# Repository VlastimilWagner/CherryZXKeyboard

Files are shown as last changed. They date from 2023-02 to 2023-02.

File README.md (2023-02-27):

# CherryZXKeyboard

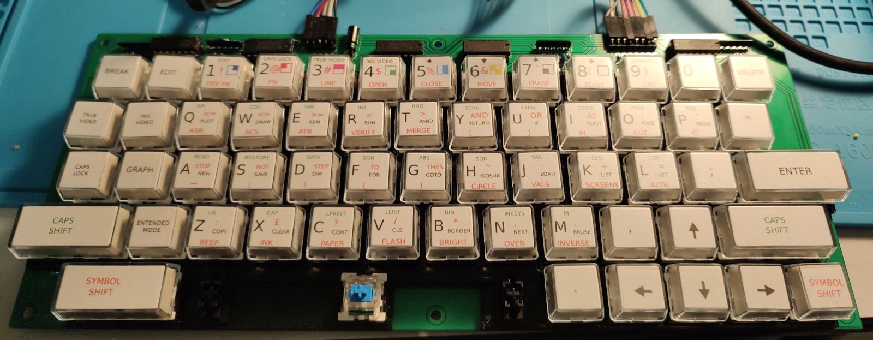
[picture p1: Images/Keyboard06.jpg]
Keyboard


The goal of the project was to create a keyboard consisting of Cherry MX keys with two-layer keycaps, into which printed labels will be inserted. At the same time, I wanted the keyboard to have a better layout of the keys (for example, cursor keys), to be easy to manufacture and install (ideally without SMD), from available components, cheap and at the same time to write well on it.

I wasn't limited to a standard format as the goal was to build a ZX MAX 128 clone and put it in my own cabinet.

Since the ZX Spectrum+ membrane is double-layered, the 48p-KDLX solution was suitable, i.e. electronically secured switching of two contacts at the same time, since the MX buttons have only one contact.

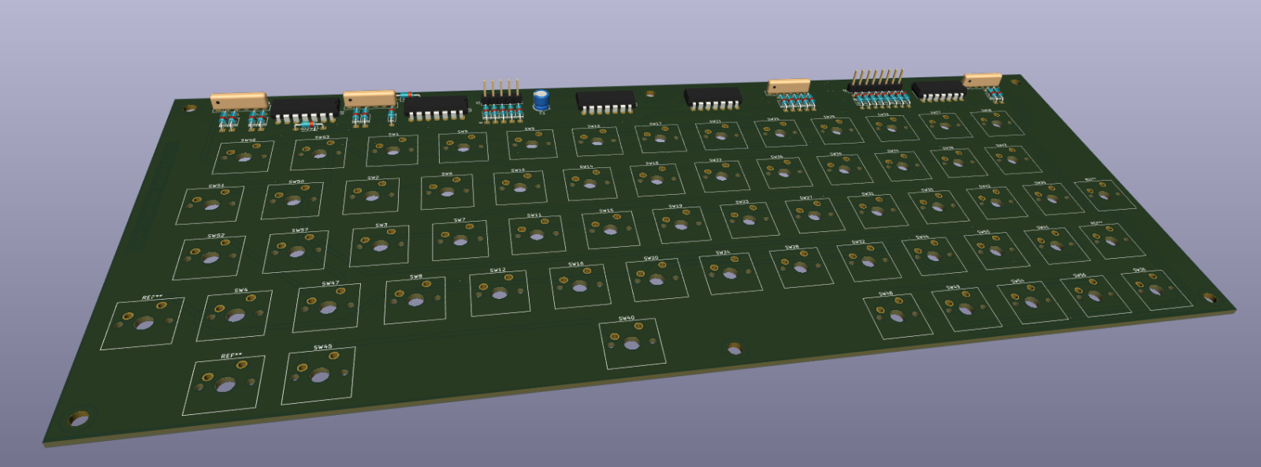
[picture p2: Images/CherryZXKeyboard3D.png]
3D


## What is needed to make

### PCB
In the [Gerber](/Gerber) directory there are materials for production. For example, on [https://jlcpcb.com](https://jlcpcb.com), just pack this directory in ZIP format, insert it into the order, and after payment, you have printed circuit boards within 2 weeks, even with the cheapest selected transport.

### Electronic Parts
These are common cheap parts from a local dealer - for example TME.
* 30 pcs Diode BAT42
* 1 pc Electrolytic capacitor 10u
* 5 pcs Resistor network (6x-1-104LF) 
* 5 pcs 74HC4066
* 5 pcs DIP14 socket

### Mechanical MX Switches (62 pcs) [AliExpress](https://www.aliexpress.com/item/1005004285423123.html )
You can use the original, but rather expensive Cherry MX, or, like me, a copy of the MX switches from AliExpress.
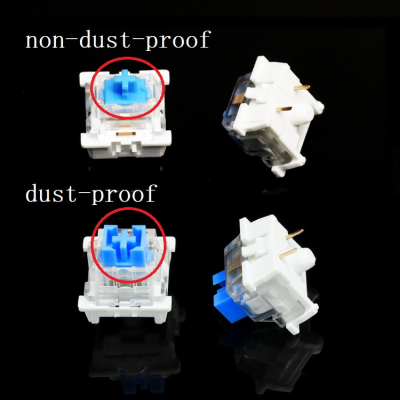
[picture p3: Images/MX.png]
MX


### Keycaps
Three types of keycaps are used:

#### - Standard buttons (53 pcs) [AliExpress](https://www.aliexpress.com/item/1005004623750938.html )
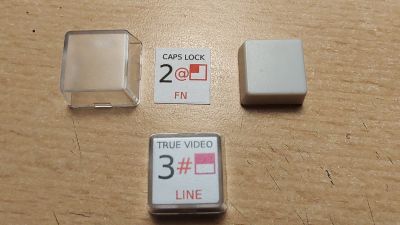
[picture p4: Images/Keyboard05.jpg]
KeyCap


#### - Wide buttons (4 pcs) [AliExpress](https://www.aliexpress.com/item/1005003201365793.html )
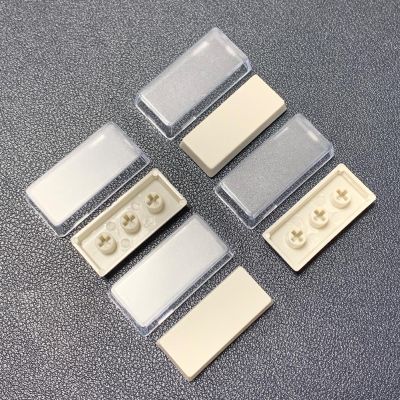
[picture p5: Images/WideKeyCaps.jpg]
WideKeyCaps


#### - Space bar 6.25u (1 pc) [AliExpress](https://www.aliexpress.com/item/1005003211865080.html )
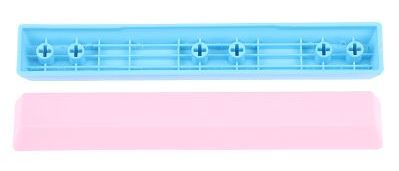
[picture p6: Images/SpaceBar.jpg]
SpaceBar


### Mechanical stabilizer for spacebar 6.25u (1 pc) [AliExpress](https://www.aliexpress.com/item/1005002552011081.html )
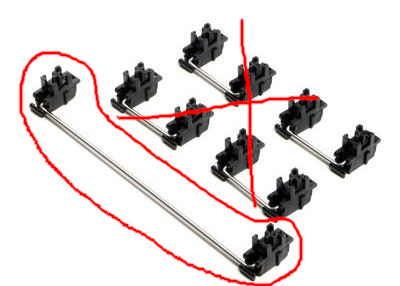
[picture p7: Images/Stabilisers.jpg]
Stabilisers


### 3D printed inserts
I divided the printing of the mat into 2 parts so that it would not be a problem to print it on a standard size 3D printer. The documents in STL format are in the [Stl](./Stl) directory.

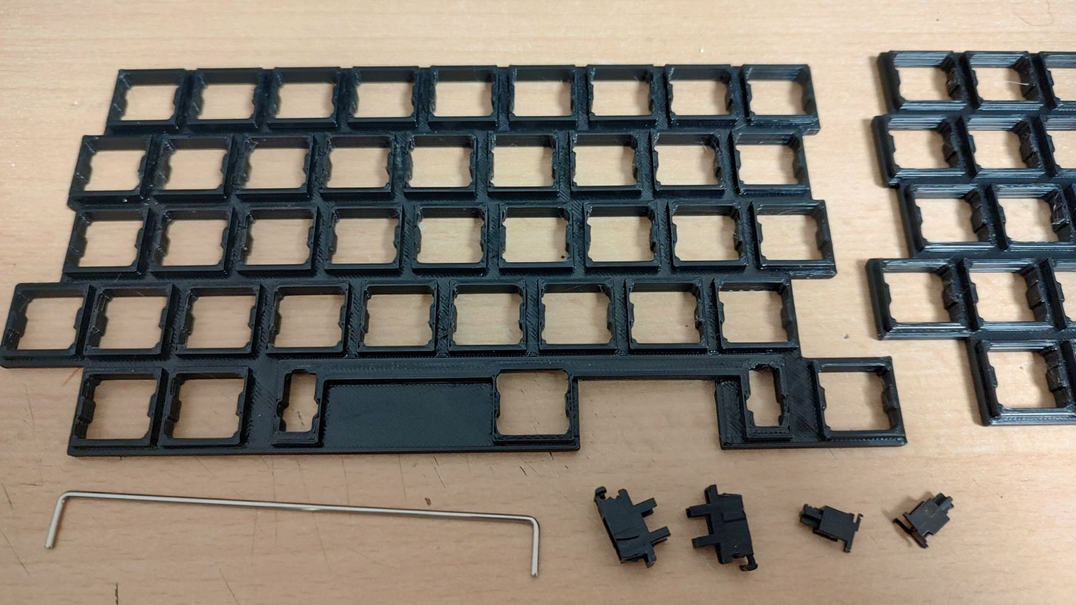
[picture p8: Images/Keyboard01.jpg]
Printed01

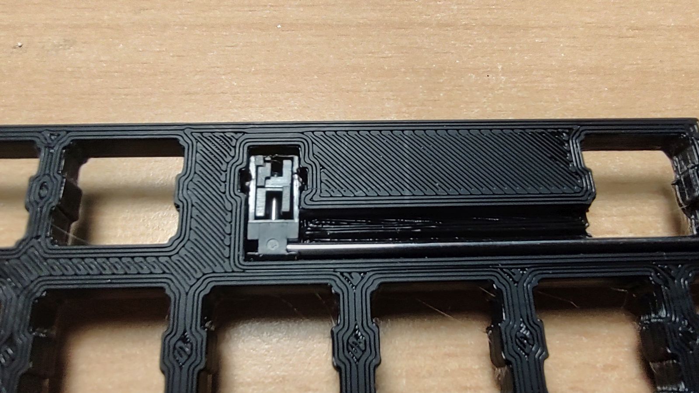
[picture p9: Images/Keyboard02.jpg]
Printed02

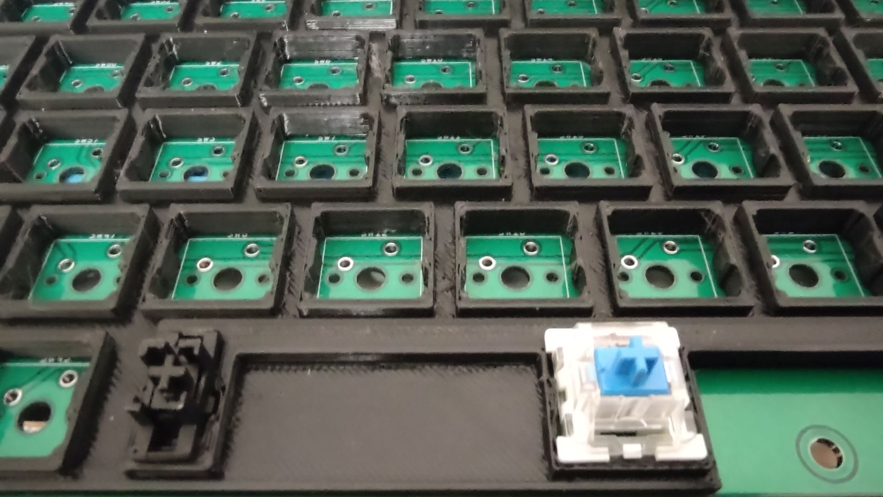
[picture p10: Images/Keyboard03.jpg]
Printed03

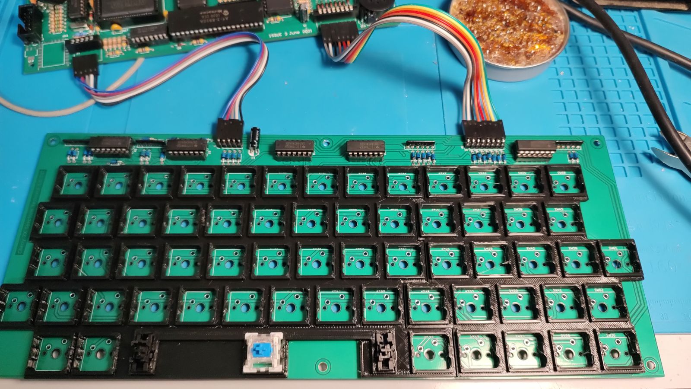
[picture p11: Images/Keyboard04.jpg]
Printed04


### Labels
The labels were drawn in Inkscape and can be printed on any color printer on plain office paper. File in SVG format is in [Labels](./Labels) directory.
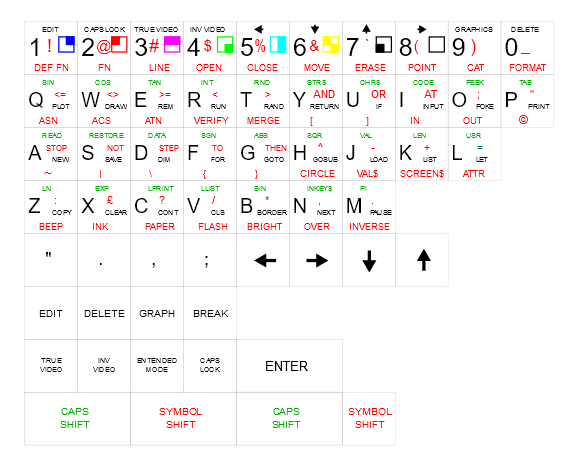
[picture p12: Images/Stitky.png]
Stitky


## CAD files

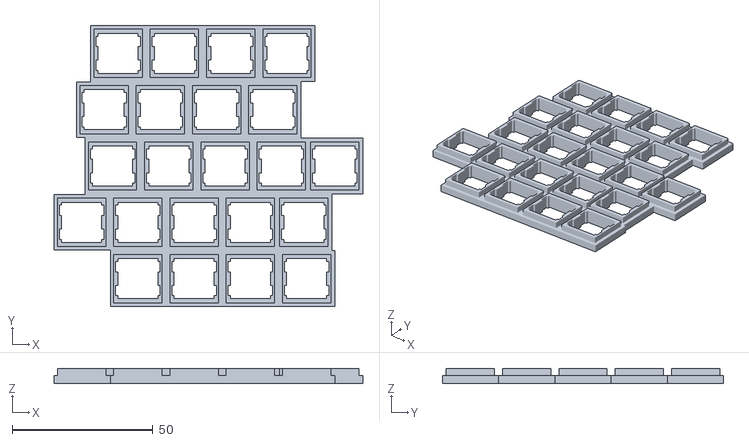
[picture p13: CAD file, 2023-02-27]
Stl/Right.stl
109.8 x 100.0 x 5.50

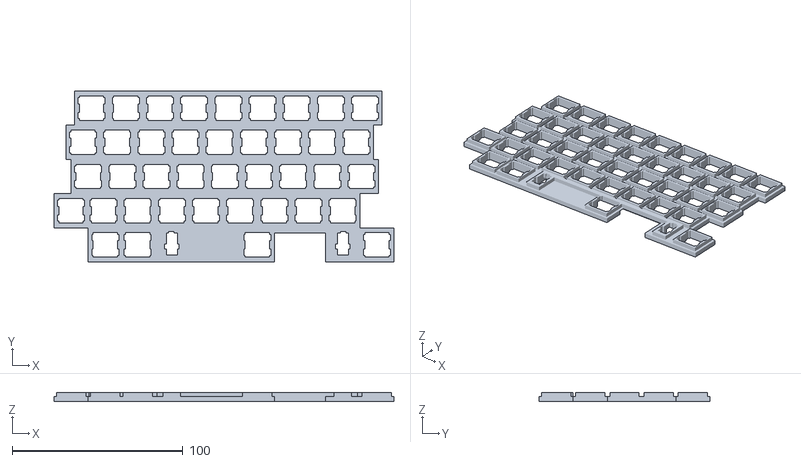
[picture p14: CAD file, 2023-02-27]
Stl/Left.stl
199.0 x 100.0 x 5.50

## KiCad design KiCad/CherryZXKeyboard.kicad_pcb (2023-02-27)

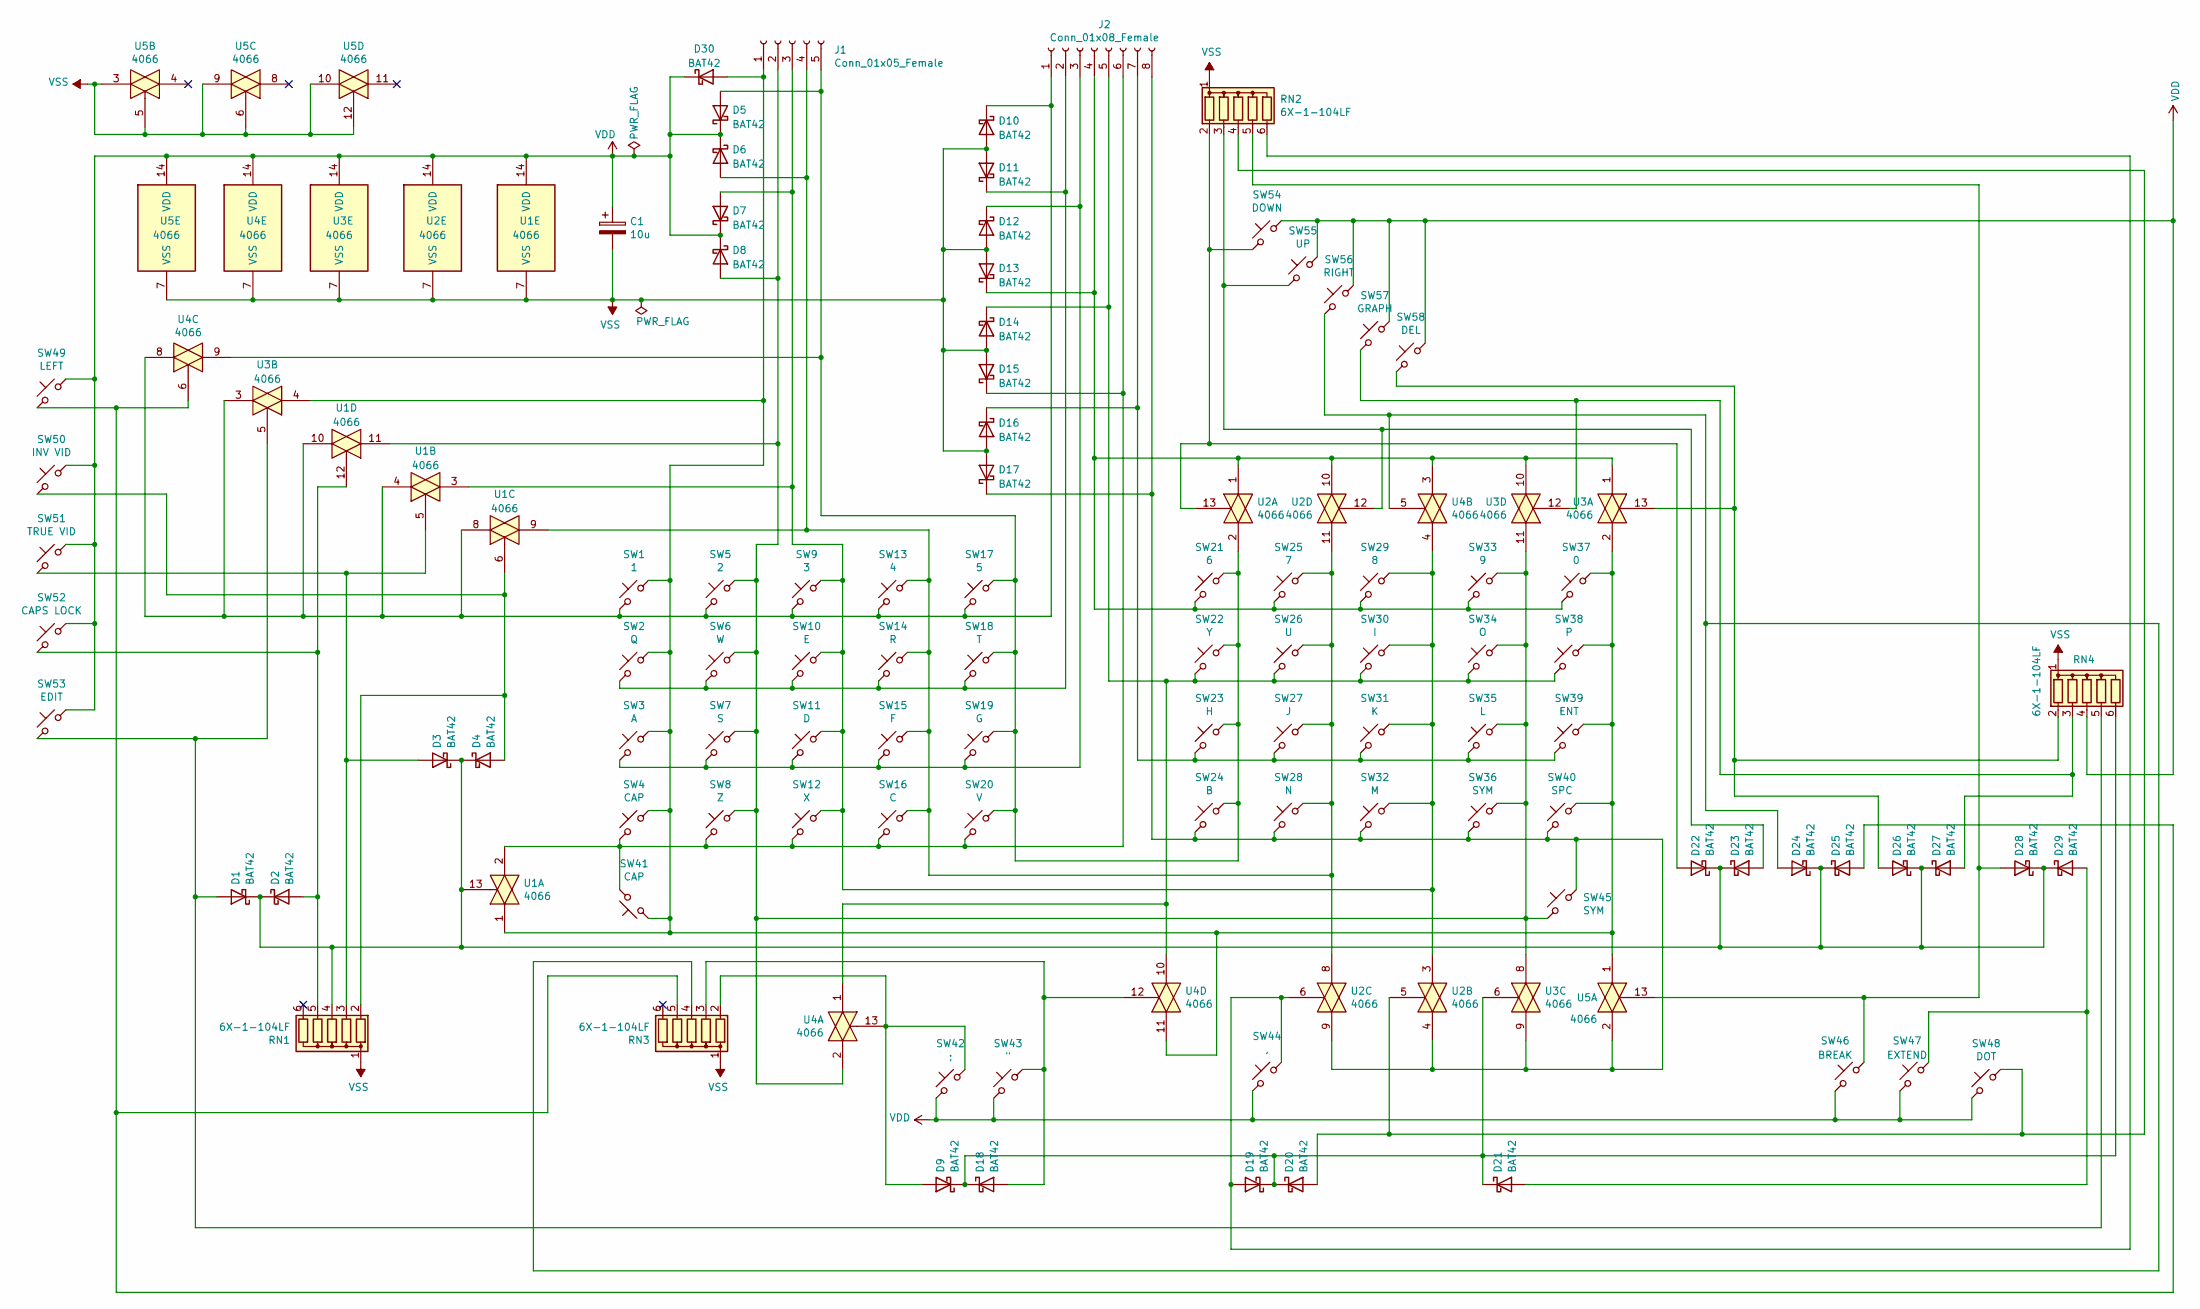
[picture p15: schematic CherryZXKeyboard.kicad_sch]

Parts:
C1: 10u; CP_Radial_D5.0mm_P2.50mm
D1, D2, D3, D4, D5, D6, D7, D8, D9, D10, D11, D12, D13, D14, D15, D16, D17, D18, D19, D20, D21, D22, D23, D24, D25, D26, D27, D28, D29, D30: BAT42; D_DO-35_SOD27_P7.62mm_Horizontal
J1: Conn_01x05_Female; PinHeader_1x05_P2.54mm_Vertical
J2: Conn_01x08_Female; PinHeader_1x08_P2.54mm_Vertical
RN1, RN2, RN3, RN4: 6X-1-104LF; R_Array_SIP6
SW1: 1; SW_Cherry_MX_1.00u_PCB
SW2: Q; SW_Cherry_MX_1.00u_PCB
SW3: A; SW_Cherry_MX_1.00u_PCB
SW4, SW41: CAP; SW_Cherry_MX_1.00u_PCB
SW5: 2; SW_Cherry_MX_1.00u_PCB
SW6: W; SW_Cherry_MX_1.00u_PCB
SW7: S; SW_Cherry_MX_1.00u_PCB
SW8: Z; SW_Cherry_MX_1.00u_PCB
SW9: 3; SW_Cherry_MX_1.00u_PCB
SW10: E; SW_Cherry_MX_1.00u_PCB
SW11: D; SW_Cherry_MX_1.00u_PCB
SW12: X; SW_Cherry_MX_1.00u_PCB
SW13: 4; SW_Cherry_MX_1.00u_PCB
SW14: R; SW_Cherry_MX_1.00u_PCB
SW15: F; SW_Cherry_MX_1.00u_PCB
SW16: C; SW_Cherry_MX_1.00u_PCB
SW17: 5; SW_Cherry_MX_1.00u_PCB
SW18: T; SW_Cherry_MX_1.00u_PCB
SW19: G; SW_Cherry_MX_1.00u_PCB
SW20: V; SW_Cherry_MX_1.00u_PCB
SW21: 6; SW_Cherry_MX_1.00u_PCB
SW22: Y; SW_Cherry_MX_1.00u_PCB
SW23: H; SW_Cherry_MX_1.00u_PCB
SW24: B; SW_Cherry_MX_1.00u_PCB
SW25: 7; SW_Cherry_MX_1.00u_PCB
SW26: U; SW_Cherry_MX_1.00u_PCB
SW27: J; SW_Cherry_MX_1.00u_PCB
SW28: N; SW_Cherry_MX_1.00u_PCB
SW29: 8; SW_Cherry_MX_1.00u_PCB
SW30: I; SW_Cherry_MX_1.00u_PCB
SW31: K; SW_Cherry_MX_1.00u_PCB
SW32: M; SW_Cherry_MX_1.00u_PCB
SW33: 9; SW_Cherry_MX_1.00u_PCB
SW34: O; SW_Cherry_MX_1.00u_PCB
SW35: L; SW_Cherry_MX_1.00u_PCB
SW36, SW45: SYM; SW_Cherry_MX_1.00u_PCB
SW37: 0; SW_Cherry_MX_1.00u_PCB
SW38: P; SW_Cherry_MX_1.00u_PCB
SW39: ENT; SW_Cherry_MX_1.00u_PCB
SW40: SPC; SW_Cherry_MX_1.00u_PCB
SW42: ;; SW_Cherry_MX_1.00u_PCB
SW43: "; SW_Cherry_MX_1.00u_PCB
SW44: ,; SW_Cherry_MX_1.00u_PCB
SW46: BREAK; SW_Cherry_MX_1.00u_PCB
SW47: EXTEND; SW_Cherry_MX_1.00u_PCB
SW48: DOT; SW_Cherry_MX_1.00u_PCB
SW49: LEFT; SW_Cherry_MX_1.00u_PCB
SW50: INV VID; SW_Cherry_MX_1.00u_PCB
SW51: TRUE VID; SW_Cherry_MX_1.00u_PCB
SW52: CAPS LOCK; SW_Cherry_MX_1.00u_PCB
SW53: EDIT; SW_Cherry_MX_1.00u_PCB
SW54: DOWN; SW_Cherry_MX_1.00u_PCB
SW55: UP; SW_Cherry_MX_1.00u_PCB
SW56: RIGHT; SW_Cherry_MX_1.00u_PCB
SW57: GRAPH; SW_Cherry_MX_1.00u_PCB
SW58: DEL; SW_Cherry_MX_1.00u_PCB
U1, U2, U3, U4, U5: 4066; DIP-14_W7.62mm_LongPads

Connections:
unnamed: D1.1 (K), D2.1 (K), D3.1 (K), D4.1 (K), D22.1 (K), D23.1 (K), D24.1 (K), D25.1 (K), D26.1 (K), D27.1 (K), D28.1 (K), D29.1 (K), RN1.4 (R3), U1.13
unnamed: D1.2 (A), RN4.5 (R4), SW53.2, U3.5
unnamed: D2.2 (A), RN1.5 (R4), SW52.2, U1.12
unnamed: D3.2 (A), RN1.3 (R2), SW51.2, U1.5
unnamed: D5.2 (A), J1.5, SW17.1, SW18.1, SW19.1, SW20.1, SW21.1, SW22.1, SW23.1, SW24.1, U2.2, U4.9
unnamed: D6.2 (A), J1.4, SW13.1, SW14.1, SW15.1, SW16.1, SW25.1, SW26.1, SW27.1, SW28.1, U1.9, U2.8, U2.11
unnamed: D7.2 (A), J1.3, SW9.1, SW10.1, SW11.1, SW12.1, SW29.1, SW30.1, SW31.1, SW32.1, U1.3, U2.3, U4.4
unnamed: D8.2 (A), J1.2, SW5.1, SW6.1, SW7.1, SW8.1, SW33.1, SW34.1, SW35.1, SW36.1, SW45.1, U1.11, U3.8, U3.11, U4.2
unnamed: D9.2 (A), RN3.2 (R1), SW42.1, U4.13
unnamed: D10.1 (K), J2.1, SW1.2, SW5.2, SW9.2, SW13.2, SW17.2, U1.4, U1.8, U1.10, U3.3, U4.8
unnamed: D11.1 (K), J2.2, SW2.2, SW6.2, SW10.2, SW14.2, SW18.2
unnamed: D12.1 (K), J2.3, SW3.2, SW7.2, SW11.2, SW15.2, SW19.2
unnamed: D13.1 (K), J2.4, SW21.2, SW25.2, SW29.2, SW33.2, SW37.2, U2.1, U2.10, U3.1, U3.10, U4.3
unnamed: D14.1 (K), J2.5, SW22.2, SW26.2, SW30.2, SW34.2, SW38.2, U4.1, U4.10
unnamed: D15.1 (K), J2.6, SW4.2, SW8.2, SW12.2, SW16.2, SW20.2, SW41.2, U1.2
unnamed: D16.1 (K), J2.7, SW23.2, SW27.2, SW31.2, SW35.2, SW39.2
unnamed: D17.1 (K), J2.8, SW24.2, SW28.2, SW32.2, SW36.2, SW40.2, SW45.2, U2.4, U2.9, U3.9, U5.2
unnamed: D9.1 (K), D18.1 (K), D19.1 (K), D20.1 (K), D21.1 (K), RN4.6 (R5), U3.6
unnamed: D18.2 (A), RN3.3 (R2), SW43.1, U4.12
unnamed: D19.2 (A), RN2.6 (R5), SW44.1, U2.6
unnamed: D20.2 (A), RN2.4 (R3), SW48.1, U2.5
unnamed: D21.2 (A), D29.2 (A), SW47.1
unnamed: D22.2 (A), RN2.2 (R1), SW54.2, U2.13
unnamed: D23.2 (A), RN2.3 (R2), SW55.2, U2.12
unnamed: D24.2 (A), RN3.4 (R3), SW56.2, U4.5
unnamed: D25.2 (A), RN3.5 (R4), SW49.2, U4.6
unnamed: D26.2 (A), RN4.2 (R1), SW58.2, U3.13
unnamed: D27.2 (A), RN4.3 (R2), SW57.2, U3.12
unnamed: D28.2 (A), RN2.5 (R4), SW46.1, U5.13
unnamed: D30.2 (A), J1.1, SW1.1, SW2.1, SW3.1, SW4.1, SW37.1, SW38.1, SW39.1, SW40.1, SW41.1, U1.1, U3.2, U3.4, U4.11, U5.1
unnamed: D4.2 (A), RN1.2 (R1), SW50.2, U1.6
VDD: C1.1, D5.1 (K), D6.1 (K), D7.1 (K), D8.1 (K), D30.1 (K), RN4.4 (R3), SW42.2, SW43.2, SW44.2, SW46.2, SW47.2, SW48.2, SW49.1, SW50.1, SW51.1, SW52.1, SW53.1, SW54.1, SW55.1, SW56.1, SW57.1, SW58.1, U1.14 (VDD), U2.14 (VDD), U3.14 (VDD), U4.14 (VDD), U5.14 (VDD)
VSS: C1.2, D10.2 (A), D11.2 (A), D12.2 (A), D13.2 (A), D14.2 (A), D15.2 (A), D16.2 (A), D17.2 (A), RN1.1 (common), RN2.1 (common), RN3.1 (common), RN4.1 (common), U1.7 (VSS), U2.7 (VSS), U3.7 (VSS), U4.7 (VSS), U5.3, U5.5, U5.6, U5.7 (VSS), U5.9, U5.10, U5.12

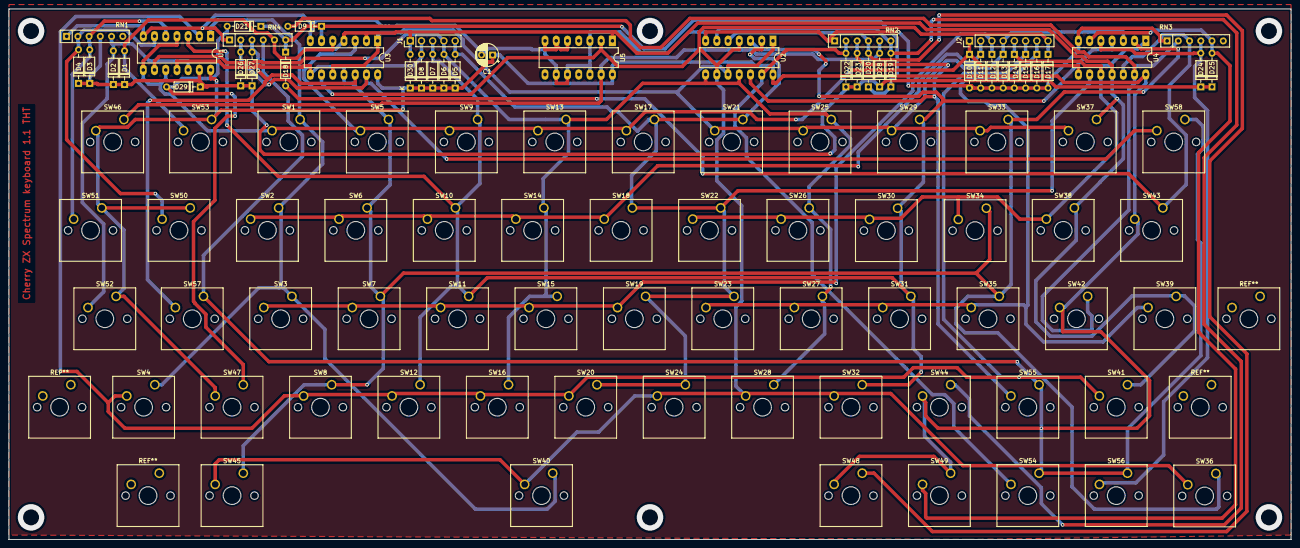
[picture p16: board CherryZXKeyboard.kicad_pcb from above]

Board: 2 copper layers, 290.0 x 120.0 mm, 100 parts (0 on the bottom side), 33 nets.

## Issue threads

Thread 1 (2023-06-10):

It's not working on my 48k issue 3 the plus keys flash the screen.

midicdj1000, 2023-06-10:
HI,

I have built up a pcb and as far as I can tell everything looks correct. The basic 48k keys are working, but the plus keys are doing some strange stuff.

Enter and space are not working
the cursor keys make the screen flash off for a moment and sometimes actually work, but not often
basically all the extra keys are doing something like this too.

Could it be the 4066 chips ? 74HC4066N, PHILIPS

does the issue of the spectrum board matter ?

VlastimilWagner, 2024-02-06:
I probably wouldn't look for a fault in a used 4066 from another manufacturer. I used SN74HC4066N, which according to the SN prefix is manufactured by TI. But the parameters are essentially the same. However, the non-functionality of ENTER and SPACE seems very strange. First of all, these keys do not use any switching via the 4066 at all, they only hard-wire the Pin of the first connector to pins 7 and 8 of the second, and in addition, no power is taken from pin 1 of the first connector to power the 4066 using diodes. Exactly these two keys must work. I would try to remove all the ICs from the sockets and test the normal keys and especially ENTER and SPACE. If they don't work even in that case, the problem will be elsewhere - a short circuit during soldering or something similar. And also check the polarity of all diodes. The functionality of the 4066 is vitally dependent on the diodes charging the capacitors from the data leads. There should be 5V across the capacitor. If the ENTER and SPACE keys start to work after removing them, I would gradually 4066 them back and find out which one is causing it - then it will be easier to find the error.

midicdj1000, 2024-02-06:
HI, I think the problem is how much power is used or provided from the spectrum boards. I tried a few and on some it worked ok and others it has problems. I have seen someone else make a PCB and they powered the chips with 5v directly is this possible without damaging the spectrum.

Another question for you, how could this be powered  when I am using a new raspbery PI zero , Pico or esp32 based spectrum board that only has 3,3v ? I am testing these boards and I would like to use the new keyboard with them, but they are not working at all. I did test it with the N-GO and it worked perfectly.

VlastimilWagner, 2024-11-26:
The original 48p-KDLX project, whose schematic was used, is intended for the ZX Spectrum+ and ZX Spectrum 128. I use it on a ZX MAX128 clone. All of these machines operate with 5V logic. However, the 74HC is used, which operates from 2V, so if you did not use the 74HCT or 74LS, which operate strictly with 5V, it could work at 3.3V, although it is stated that the 74HC reacts a little slower at lower voltages. Using an external 5V or 3.3V power supply should not be a problem. It should be enough to remove all the diodes that are connected to the input connectors and draw energy from the signal wires, and then, instead of the electrolytic capacitor to which they are connected on the other side, solder the +5V and GND wires, which will be connected to the ground and the board power supply. This will allow the circuits to directly receive power from the board and the signal wires will no longer be burdened by the draw through the diodes.

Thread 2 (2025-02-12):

occasional 0 instead of delete

Cappertil, 2025-02-12:
Hi, I am using this schematic for a PCB that follows the original spectrum + key layout and I am using this keyboard with a n-go zx next clone.

Very occasionally I get a '0' when I press delete. I seems to happen more often when the spectrum is 'over clocked' to 28MHz, so I wondered if it might be a timing issue.

However, it is hard to imagine a diode could cause much delay, nor I have never seen incorrect inputs from other CAPS keys e.g. cursor keys; or any of the symbol shift characters that also use diodes.

Maybe a real spectrum + does this sometimes? I only had experience of the 48k and +2.
